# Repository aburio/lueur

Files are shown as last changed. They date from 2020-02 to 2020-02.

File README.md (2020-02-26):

# Lueur

This repository contain the source code & hardware design of the lueur project. Lueur is a pair of internet connected cubes who can light up each other using an ESP8266, an RGB LED and AWS IoT.

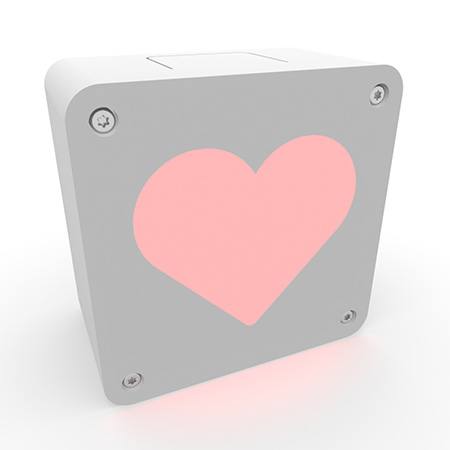
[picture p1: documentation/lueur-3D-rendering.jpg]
Lueur 3D rendering


## Build with

* [Platformio](https://platformio.org/)
* [ESP8266 core for Arduino](https://github.com/esp8266/Arduino)
* [ESPAsyncWebServer](https://github.com/me-no-dev/ESPAsyncWebServer)
* [ESPAsyncTCP](https://github.com/me-no-dev/ESPAsyncTCP)
* [pubsubclient](https://github.com/knolleary/pubsubclient)

## License

This project is licensed under the MIT License - see the [LICENSE.md](LICENSE.md) file for details

## Authors

* [Clément Aceituno](https://github.com/clementAC) - Captive portal & OTA webpage source code
* [Arthur Burnichon](https://github.com/aburio) - Firmware source code & PCB design
* Loïc Badel - Casing design

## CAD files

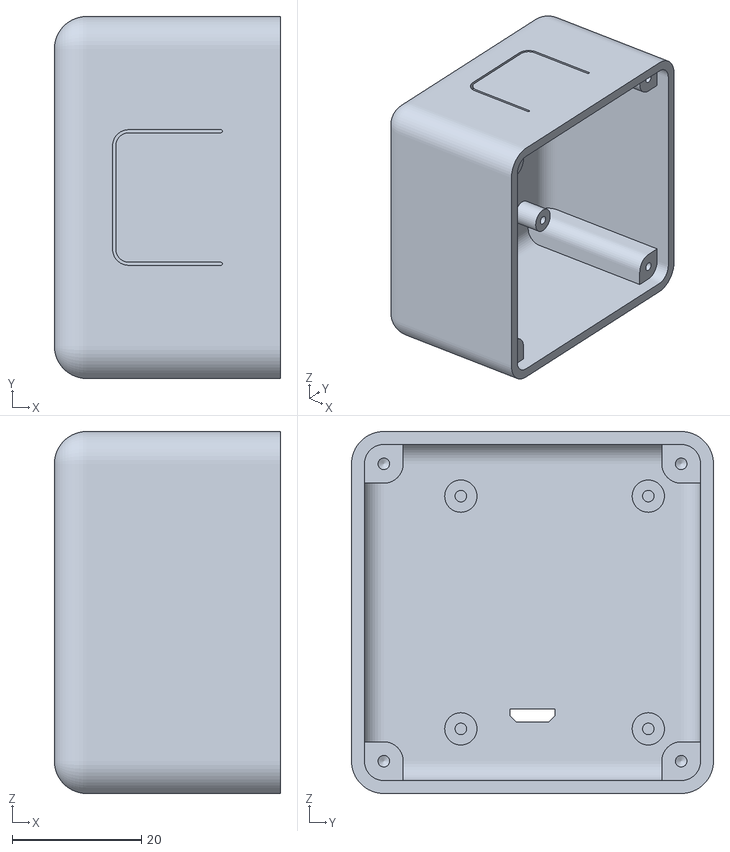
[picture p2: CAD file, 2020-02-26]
hardware/casing.stl
35.0 x 56.0 x 56.0

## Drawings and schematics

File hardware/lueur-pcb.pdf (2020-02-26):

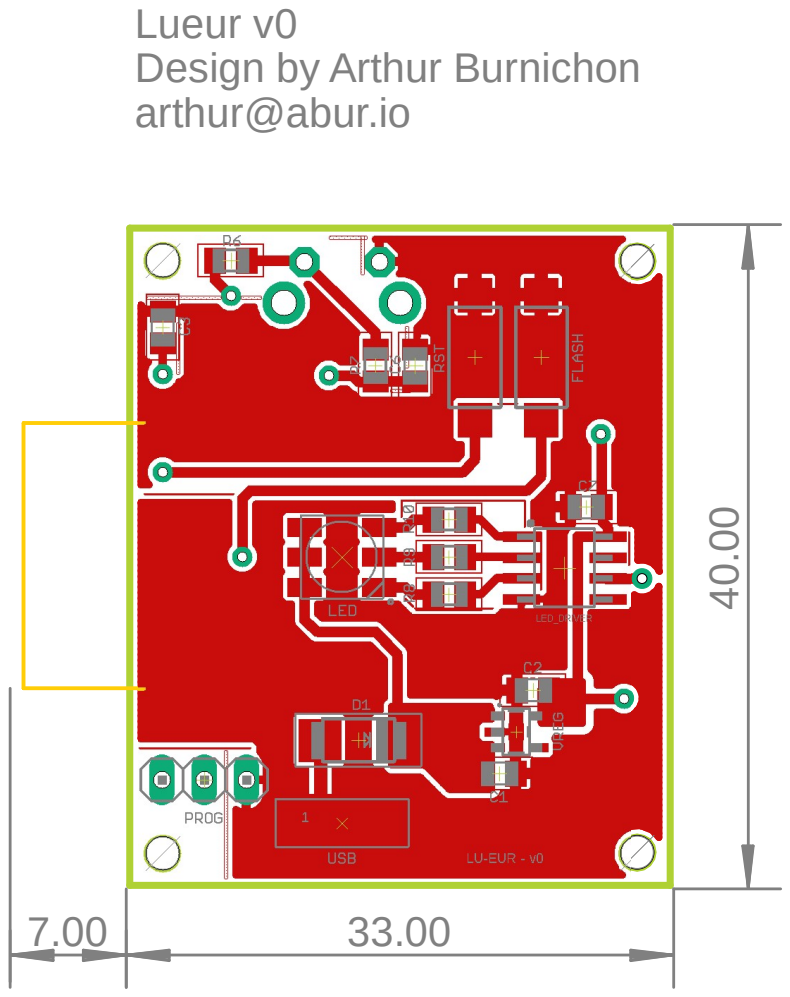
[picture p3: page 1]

Lueur v0
Design by Arthur Burnichon
arthur@abur.io

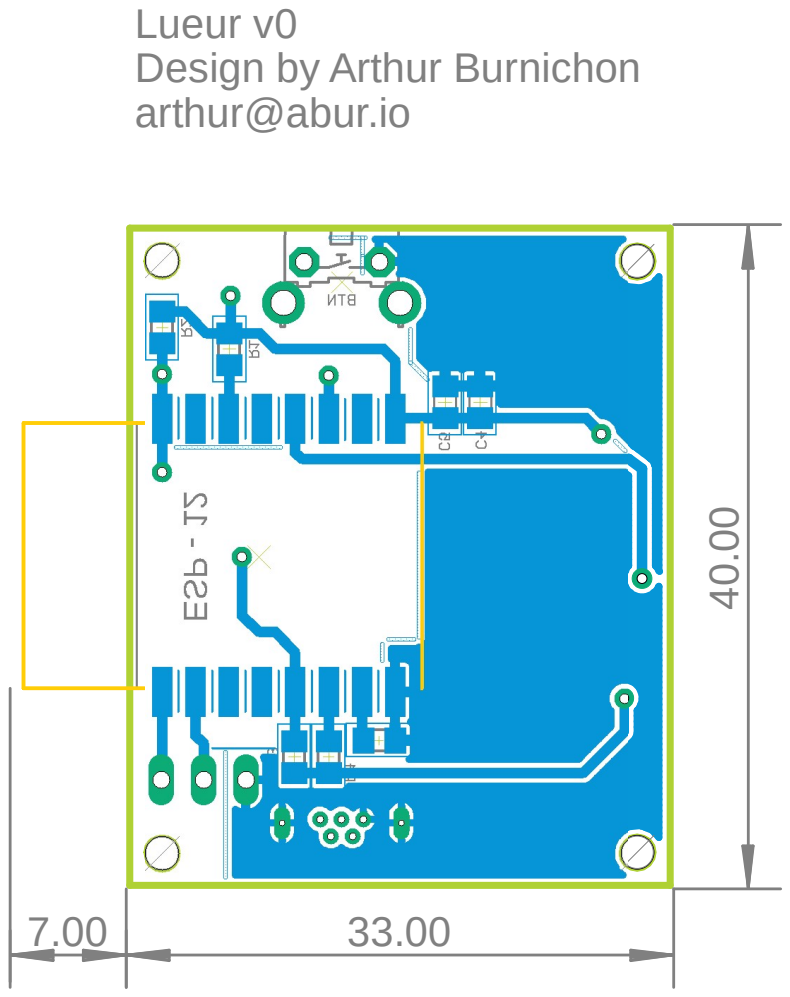
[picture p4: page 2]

Lueur v0
Design by Arthur Burnichon
arthur@abur.io

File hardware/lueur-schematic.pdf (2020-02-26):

## Paris, France USB

A

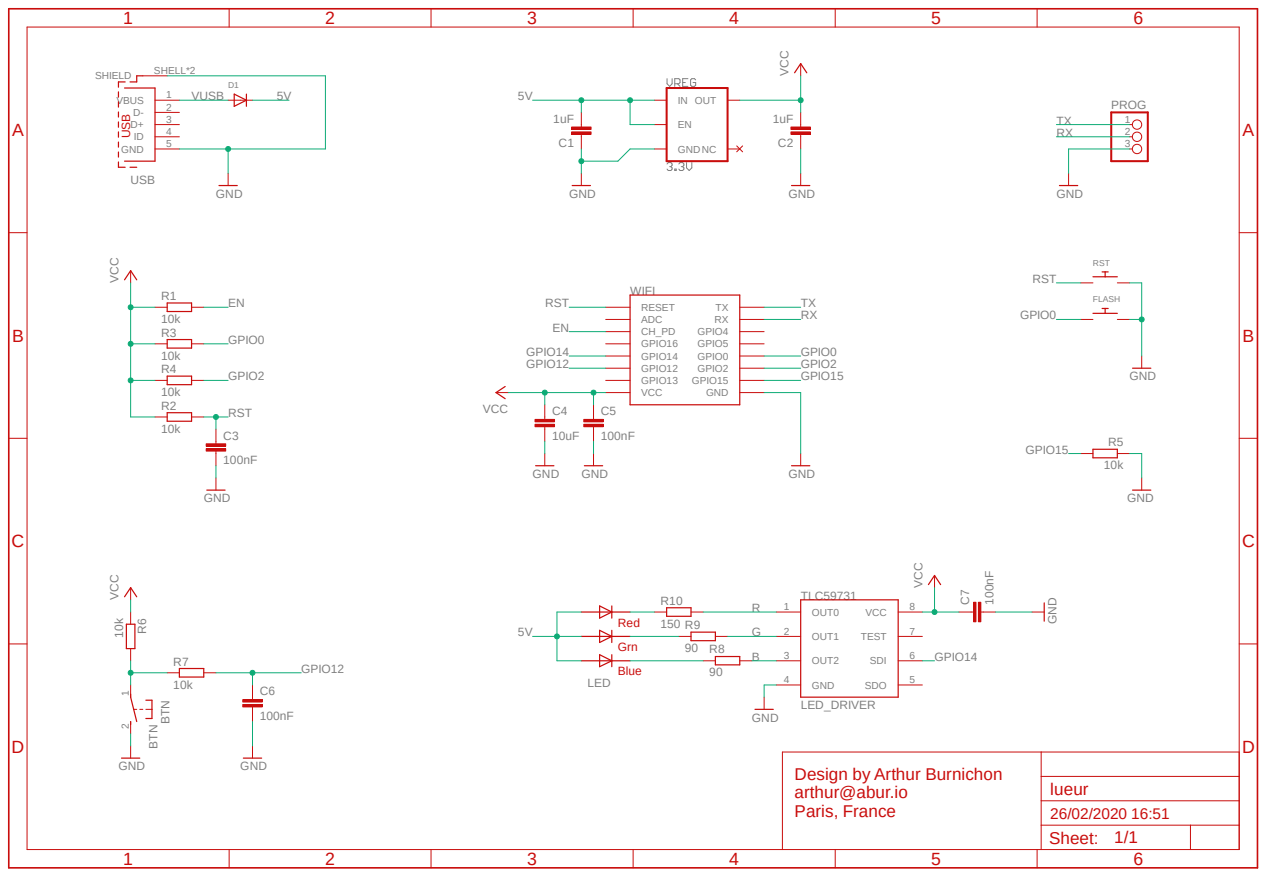
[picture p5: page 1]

RST

Design by Arthur Burnichon arthur@abur.io

Sheet: 1/1

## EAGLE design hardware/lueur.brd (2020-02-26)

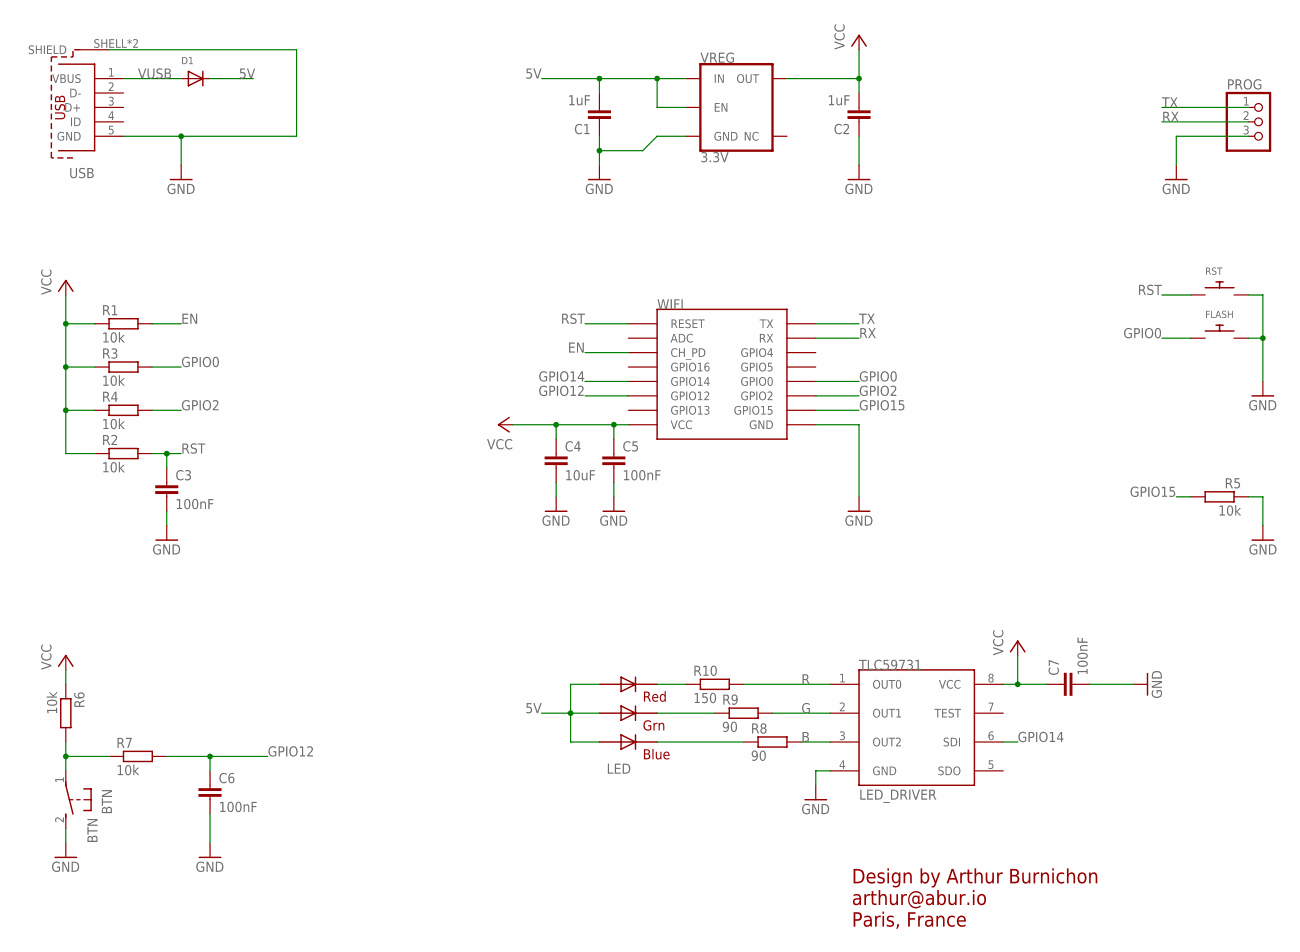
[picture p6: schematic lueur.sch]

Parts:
BTN: BTN; B3F-31XX
C1, C2: 1uF; C0805
C3, C5, C6, C7: 100nF; C0805
C4: 10uF; C0805
D1: DIODESMA; SMADIODE
FLASH: SWITCH_PUSHBUTTONSOFTTOUCHSMD_SJ; PUSHBUTTON_SMD_SJ
LED: RGB5555; RGBLED5050
LED_DRIVER: TLC59731; SOIC8
PROG: PINHD-1X3; 1X03
R1, R2, R3, R4, R5, R6, R7: 10k; R0805
R8, R9: 90; R0805
R10: 150; R0805
RST: SWITCH_PUSHBUTTONSOFTTOUCHSMD_SJ; PUSHBUTTON_SMD_SJ
USB: 614105150721
VREG: 3.3V; SOT23-5
WIFI: ESP12SMD; ESP12-SMD

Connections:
5V: C1.2, D1.C, LED.4 (RED_A), LED.5 (GREEN_A), LED.6 (BLUE_A), VREG.1 (IN), VREG.3 (EN)
B: LED_DRIVER.3 (OUT2), R8.2
BTN: BTN.1, R6.2, R7.1
EN: R1.2, WIFI.CH_PD
G: LED_DRIVER.2 (OUT1), R9.2
GND: BTN.2 (S), C1.1, C2.1, C3.2, C4.2, C5.2, C6.2, C7.2, FLASH.P$2, LED_DRIVER.4 (GND), PROG.3, R5.1, RST.P$2, USB.5 (GND), USB.SHELL (SHIELD), USB.SHELL1 (SHIELD), VREG.2 (GND), WIFI.GND
GPIO0: FLASH.P$1, R3.2, WIFI.GPIO0
GPIO2: R4.2, WIFI.GPIO2
GPIO12: C6.1, R7.2, WIFI.GPIO12
GPIO14: LED_DRIVER.6 (SDI), WIFI.GPIO14
GPIO15: R5.2, WIFI.GPIO15
unnamed: LED.3 (RED_C), R10.1
unnamed: LED.2 (GREEN_C), R9.1
unnamed: LED.1 (BLUE_C), R8.1
R: LED_DRIVER.1 (OUT0), R10.2
RST: C3.1, R2.2, RST.P$1, WIFI.RESET
RX: PROG.2, WIFI.RXD0 (RX)
TX: PROG.1, WIFI.TXD0 (TX)
VCC: C2.2, C4.1, C5.1, C7.1, LED_DRIVER.8 (VCC), R1.1, R2.1, R3.1, R4.1, R6.1, VREG.5 (OUT), WIFI.VCC
VUSB: D1.A, USB.1 (VBUS)

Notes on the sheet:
Design by Arthur Burnichon arthur@abur.io Paris, France

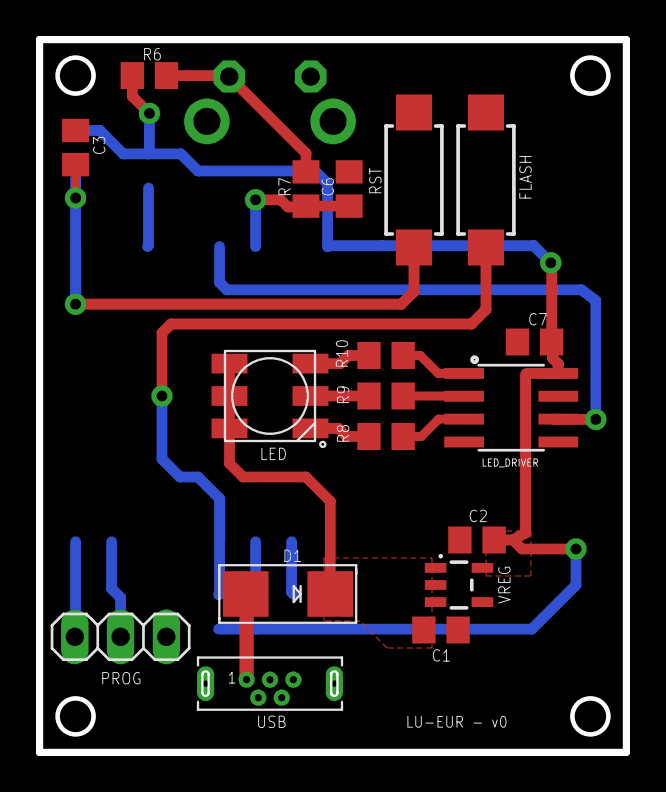
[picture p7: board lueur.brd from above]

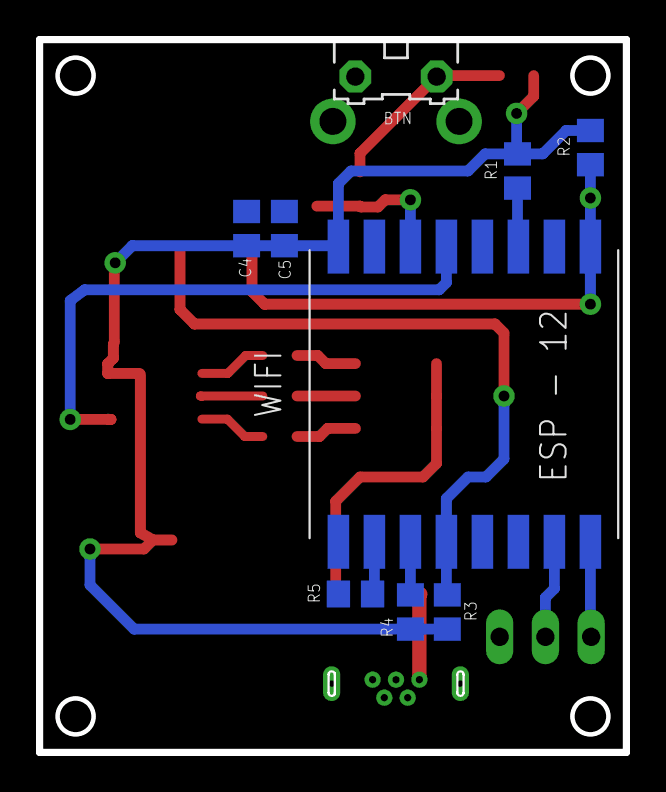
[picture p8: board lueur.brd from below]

Board: 2 copper layers, 32.6 x 39.6 mm, 27 parts (9 on the bottom side), 20 nets.

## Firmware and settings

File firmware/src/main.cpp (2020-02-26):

#include "data.h"
#include "wifi.h"
#include "ota.h"
#include "mqtt.h"
#include "led.h"
#include "button.h"

WiFiClientSecure *tls_client;
bool wait_user = false;
bool wait_ack = false;
uint32_t ack_timeout;
String pair_topic = "null";
String pair_id = "null";

//------------------
// Setup TLS
//------------------
bool SetupTlsConnection(WiFiClientSecure* client)
{
  bool result = true;

  return  result;
}

//------------------
// Startup section
//------------------
void setup() {
  bool result;

  Serial.begin(115200);
  Serial.println(String(ESP.getChipId()));

  SPIFFS.begin();
  LedInit(LED_PIN);
  ButtonInit(BUTTON_PIN);
  WifiInit();

  tls_client = new WiFiClientSecure();

  // Load certificate file
  File cert = SPIFFS.open("/cert/cert.der", "r"); //replace cert.crt eith your uploaded file name
  if (!cert) {
    Serial.println("Failed to open cert file");
    LedBlink(0x0000FF, 500);
    result = false;
  }
  else {
    result = tls_client->loadCertificate(cert);
    if (!result) {
      Serial.println("Failed to load cert file");
    }
  }

  // Load private key file
  File private_key = SPIFFS.open("/cert/privatekey.der", "r"); //replace private eith your uploaded file name
  if (!private_key) {
    Serial.println("Failed to open private cert file");
    result = false;
  }
  else {
    result = tls_client->loadPrivateKey(private_key);
    if (!result) {
      Serial.println("Failed to load private key file");
    }
  }

  if (result) {
    MqttInit(kMqttDomain, kMqttPort, kDeviceId, *tls_client);
  }
  else {
    Serial.println("Cert shall be update to establish MQTT connection");
  }
}

//-----------------
// Main section
//-----------------
void loop() {
  ButtonProcess();
  WifiProcess();
  if (wait_ack && ack_timeout <= millis()) {
    LedBlink(LED_ERROR_COLOR, 1000 ,1);
    wait_ack = false;
  }
  yield();
}

//-----------------
// Wifi Callback section
//-----------------
void WifiCaptivePortalStartCallBack() {
  LedOn(LED_CONFIG_COLOR);
}

void WifiCaptivePortalEndCallBack() {
  LedOff();
  delay(500);
  ESP.restart();
}

void WifiWaitingConnectionCallBack() {
  LedBlink(LED_ERROR_COLOR, LED_ERROR_PERIOD);
}

void WifiProcessCallBack() {
  MqttProcess();
}

//-----------------
// Device section
//-----------------

void DeviceInboxMessage(String message) {
  if (message == "0" && wait_ack) {
    // Pair message acknowledgment
    wait_ack = false;
    LedFade((uint32_t)0xFF0000, 20, 2); // Heart beat
  }
  else if (message == pair_id) {
    // New message from pair
    MqttSend(pair_topic,"0"); // acknowledgment
    LedFadeIn((uint32_t)0xFF0000, 50); // light on
    wait_user = true;
  }
  else if (message.startsWith(kBaseTopic)) {
    // Pairing information received
    File f = SPIFFS.open(kPairingFile, "w");

    if (f) {
      pair_topic = message;
      pair_id = message.substring(message.lastIndexOf('/') + 1);
      f.println(pair_topic);
      f.close();
    }
  }
}

//-----------------
// Maintenance section
//-----------------

void MaintenanceUpdateStatus(const String update_name, OtaStatus status) {
  if (status == SUCCESS) {
    MqttSend(kDeviceStatusTopic, update_name + " updated");
  }
  else if (status == UP_TO_DATE) {
    MqttSend(kDeviceStatusTopic, update_name + " up to date");
  }
  else {
    MqttSend(kDeviceStatusTopic, update_name + " failed to update");
  }
}

void MaintenanceUpdate() {
  MqttSend(kDeviceStatusTopic, "update");
  LedRainbow(50);

  OtaStatus spiffs_status = OtaSpiffsUpdate(kUpdateServer);
  MaintenanceUpdateStatus("spiffs", spiffs_status);

  OtaStatus app_status = OtaAppUpdate(kUpdateServer);
  MaintenanceUpdateStatus("app", app_status);

  if (app_status != FAILED && spiffs_status != FAILED) {
    LedBlink(LED_UPDATE_COLOR, LED_UPDATE_PERIOD, 3);

    // Si un des composants a été mise à jour on redémarre
    if (app_status == SUCCESS || spiffs_status == SUCCESS) {
      delay(1600);
      ESP.restart();
    }
  }
  else {
    LedBlink(LED_ERROR_COLOR, LED_ERROR_PERIOD, 3);
  }
}

void MaintenanceBuildInfo() {
  MqttSend(kDeviceStatusTopic, kBuildCommit);
}

void MaintenanceTimeInfo() {
  uint32_t rtc_period = system_rtc_clock_cali_proc();
  uint32_t rtc_period_int_part = rtc_period >> 12;
  uint32_t rtc_period_dec_part = rtc_period & 0x00000FFF;
  uint32_t rtc_count = system_get_rtc_time();
  uint32_t up_time = system_get_time();
  String rst_reason = ESP.getResetReason();
  MqttSend(kDeviceStatusTopic, "Last reset reason : " + rst_reason);
  MqttSend(kDeviceStatusTopic, "Up time : " + String(up_time) + "us");
  MqttSend(kDeviceStatusTopic, "RTC period : " + String(rtc_period_int_part) + "." + String(rtc_period_dec_part) + "us");
  MqttSend(kDeviceStatusTopic, "RTC count : " + String(rtc_count));
}

void MaintenanceMemoryInfo() {
  uint8_t flash_mode = ESP.getFlashChipMode();
  uint32_t flash_speed = ESP.getFlashChipSpeed() / 1000000;
  uint32_t flash_size = ESP.getFlashChipRealSize() / 1024;

  MqttSend(kDeviceStatusTopic, "Flash size : " + String(flash_size) + " Kb");
  MqttSend(kDeviceStatusTopic, "Flash speed : " + String(flash_speed) + "MHz");

  switch (flash_mode) {
    case 0x00:
      MqttSend(kDeviceStatusTopic, "Flash mode : QIO");
      break;
    case 0x01:
      MqttSend(kDeviceStatusTopic, "Flash mode : QOUT");
      break;
    case 0x02:
      MqttSend(kDeviceStatusTopic, "Flash mode : DIO");
      break;
    case 0x03:
      MqttSend(kDeviceStatusTopic, "Flash mode : DOUT");
      break;
    default:
      MqttSend(kDeviceStatusTopic, "Flash mode : Unknow");
  }

  MqttSend(kDeviceStatusTopic, "Free program memory : " + String(ESP.getFreeSketchSpace()) + " bytes");
  MqttSend(kDeviceStatusTopic, "Free heap : " + String(ESP.getFreeHeap()) + " bytes");
}

void MaintenanceNetwork() {
  MqttSend(kDeviceStatusTopic, "SSID : " + WiFi.SSID());
  MqttSend(kDeviceStatusTopic, "RSSI : " + String(WiFi.RSSI()) + "dB");
  MqttSend(kDeviceStatusTopic, "Channel : " + String(WiFi.channel()));
  MqttSend(kDeviceStatusTopic, "MAC Address : " + WiFi.macAddress());
}

void MaintenanceInboxMessage(String message) {
  if (message == "0") {
    MaintenanceUpdate();
  }
  else if (message == "1") {
    MaintenanceBuildInfo();
  }
  else if (message == "2") {
    MaintenanceTimeInfo();
  }
  else if (message == "3") {
    MaintenanceMemoryInfo();
  }
  else if (message == "4") {
    MaintenanceNetwork();
  }
}

//-----------------
// Mqtt Callback section
//-----------------
void MqttConnectionCallBack() {
  Serial.println("Connected");
  LedOff();
  MqttSubscribe(kDeviceTopic);
  MqttSubscribe(kMaintenanceTopic);
  MqttSend(kBuildTopic, kId + "/" + kBuildCommit);

  if (!SPIFFS.exists(kPairingFile.c_str())) {
    MqttSend(kWelcomeTopic, kId);
  } else {
    File f = SPIFFS.open(kPairingFile.c_str(), "r");
    if (f) {
      pair_topic = f.readStringUntil('\n');
      pair_topic.remove(pair_topic.length() - 1);
      MqttSend(kWelcomeTopic, kId + "-" + pair_topic);
      pair_id = pair_topic.substring(pair_topic.lastIndexOf('/') + 1);
    }
  }
}

void MqttReceivedCallBack(String topic, byte* payload, uint32_t length) {
  Serial.println("Message received");
  if (length > 0) {
    char* message = new char[length];
    memcpy(message, payload, length);
    message[length] = 0;

    if (topic == kDeviceTopic) {
      DeviceInboxMessage(message);
    }
    else if (topic == kMaintenanceTopic) {
      MaintenanceInboxMessage(message);
    }

    delete message;
  }
}

void MqttDisconnectedCallBack() {
  Serial.println("Mqtt connection lost");
  LedBlink(LED_ERROR_COLOR, LED_ERROR_PERIOD);
}

//-----------------
// Button Callback section
//-----------------
void ButtonClickCallBack() {
  if (wait_user == true) {
    wait_user = false;
    LedOff();
  }
  else if (pair_id != "null") {
    // Send a message to the pair
    MqttSend(pair_topic, kId);
    wait_ack = true;
    ack_timeout = millis() + ACKNOWLEDGE_TIMEOUT;
  } else {
    // Led turn on for 1 second
    LedBlink(LED_ERROR_COLOR, 1000 ,1);
  }
}

void ButtonDoubleClickCallBack() {
  wait_user = false;

  if (pair_id != "null") {
    // Send a message to the pair
    MqttSend(pair_topic, kId);
    wait_ack = true;
    ack_timeout = millis() + ACKNOWLEDGE_TIMEOUT;
  } else {
    // Led turn on for 1 second
    LedBlink(LED_ERROR_COLOR, 2000 ,1);
  }
}

void ButtonLongPressCallBack() {
  MaintenanceUpdate();
}

void ButtonResetCallBack() {
  WiFi.disconnect(true);
  SPIFFS.begin();
  if (SPIFFS.exists(kPairingFile.c_str())) {
    SPIFFS.remove(kPairingFile.c_str());
  }
}

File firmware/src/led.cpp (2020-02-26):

#include "led.h"

struct LedParameters {
  uint32_t nb_iteration = 0;
  uint32_t iteration = 0;
};

LedParameters led_param;
Ticker led_tick;

Tlc59731 led;

void LedInit(int pin) {
  led = Tlc59731(pin);
  led.setBrightness(LED_BRIGHT);
  led.clear();
  led.show();
}

void ICACHE_RAM_ATTR LedToggle(uint32_t color) {
  if ((led_param.nb_iteration != 0) && (led_param.iteration >= led_param.nb_iteration)) {
    LedOff();
  }
  else if (led.getColor() == 0) {
    led.setColor(color);
  }
  else {
    led.clear();
  }

  led.show();

  if (led_param.nb_iteration != 0) {
    led_param.iteration++;
  }
}

void LedBlink(uint32_t color, uint32_t period) {
  LedBlink(color, period, 0);
}

void LedBlink(uint32_t color, uint32_t period, uint8_t nb_blink) {
  led_tick.detach(); //Stop previous blink or rainbow
  if (nb_blink != 0) {
    led_param.nb_iteration = nb_blink * 2;
  }
  else {
    led_param.nb_iteration = 0;
  }
  led_param.iteration = 0;
  led_tick.attach_ms(period, LedToggle, color);
}

void ICACHE_RAM_ATTR LedColorWheel() {
  if (led_param.iteration < 256) {
    byte WheelPos = (255 - led_param.iteration) & 255;
    if (WheelPos < 85) {
      led.setColor(255 - WheelPos * 3, 0, WheelPos * 3);
    } 
    else if (WheelPos < 170) {
      WheelPos -= 85;
      led.setColor(0, WheelPos * 3, 255 - WheelPos * 3);
    }
    else {
      WheelPos -= 170;
      led.setColor(WheelPos * 3, 255 - WheelPos * 3, 0);
    }
    led_param.iteration ++;
  }
  else {
    led_param.iteration = 0;
  }
  led.show();
}

void ICACHE_RAM_ATTR LedColorIn(uint32_t color) {
  uint8_t red = ((uint8_t)(color >> 16) * led_param.iteration) >> 8;
  uint8_t green = ((uint8_t) (color >>  8) * led_param.iteration) >> 8;
  uint8_t blue = ((uint8_t) color * led_param.iteration) >> 8;
  
  if (led_param.iteration < 255) {
    led_param.iteration += 3;
  }
  else {
    led_param.iteration = 0;
    led_tick.detach();
  }
  
  led.setColor(red, green, blue);
  led.show();
}

void ICACHE_RAM_ATTR LedColorOut(uint32_t color) {
  uint8_t red =  ((uint8_t)(color >> 16) * (255 - led_param.iteration)) >> 8;
  uint8_t green = ((uint8_t) (color >>  8) * (255 -led_param.iteration)) >> 8;
  uint8_t blue = ((uint8_t) color * (255 - led_param.iteration)) >> 8;
  
  if (led_param.iteration < 255) {
    led_param.iteration += 3;
  }
  else {
    led_param.iteration = 0;
    led_tick.detach();
  }
  
  led.setColor(red, green, blue);
  led.show();
}

void ICACHE_RAM_ATTR LedColorInOut(uint32_t color) {
  uint8_t red = (uint8_t) (color >> 16);
  uint8_t green = (uint8_t) (color >>  8);
  uint8_t blue = (uint8_t) color;

  if ((led_param.nb_iteration != 0) && (led_param.iteration > led_param.nb_iteration)) {
    LedOff();
  }
  else if (led_param.iteration % 2 == 0) {
    // Fade Out
    red = (red * (led.getRedValue() - 3)) >> 8;
    green = (green * (led.getGreenValue() - 3)) >> 8;
    blue = (blue * (led.getBlueValue() - 3)) >> 8;
    led.setColor(red, green, blue);
    if (led.getColor() == 0) {
      led_param.iteration++;
    }
  }
  else {
    // Fade In
    red = (red * (led.getRedValue() + 3)) >> 8;
    green = (green * (led.getGreenValue() + 3)) >> 8;
    blue = (blue * (led.getBlueValue() + 3)) >> 8;
    led.setColor(red, green, blue);
    if (led.getColor() == color) {
      led_param.iteration++;
    }
  }

  led.show();
}



void LedRainbow(uint32_t delay_ms) {
  led_tick.detach(); //Stop previous blink or rainbow
  led_param.iteration = 0;
  led_tick.attach_ms(delay_ms, LedColorWheel);
}

void LedFadeIn(uint32_t color, uint32_t delay_ms) {
  led_tick.detach();
  led_param.iteration = 0;
  led_tick.attach_ms(delay_ms, LedColorIn, color);
}

void LedFadeOut(uint32_t color, uint32_t delay_ms) {
  led_tick.detach();
  led_param.iteration = 0;
  led_tick.attach_ms(delay_ms, LedColorOut, color);
}

void LedFade(uint32_t color, uint32_t delay_ms) {
  LedFade(color, delay_ms, 0);
}

void LedFade(uint32_t color, uint32_t delay_ms, uint8_t nb_fade) {
  led_tick.detach();
  if (nb_fade != 0) {
    led_param.nb_iteration = nb_fade * 2;
  }
  else {
    led_param.nb_iteration = 0;
  }
  led_param.iteration = 1; // For consistency with fade count
  led_tick.attach_ms(delay_ms, LedColorInOut, color);
}

void LedOn(uint32_t color) {
  led_tick.detach(); //Stop previous blink or rainbow
  led.setColor(color);
  led.show();
}

void LedOff() {
  led_tick.detach();
  led.clear();
  led.show();
}

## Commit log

2020-02-26 📩 Import of the Lueur project from Luseed (www.luseed.io) Bitbucket private repository to Github
    [casing.stl, lueur.brd, lueur.sch]
2020-02-26 📸 Fix of the README image

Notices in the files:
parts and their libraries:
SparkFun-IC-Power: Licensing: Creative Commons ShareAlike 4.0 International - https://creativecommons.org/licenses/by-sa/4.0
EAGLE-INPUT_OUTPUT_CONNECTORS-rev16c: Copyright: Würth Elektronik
